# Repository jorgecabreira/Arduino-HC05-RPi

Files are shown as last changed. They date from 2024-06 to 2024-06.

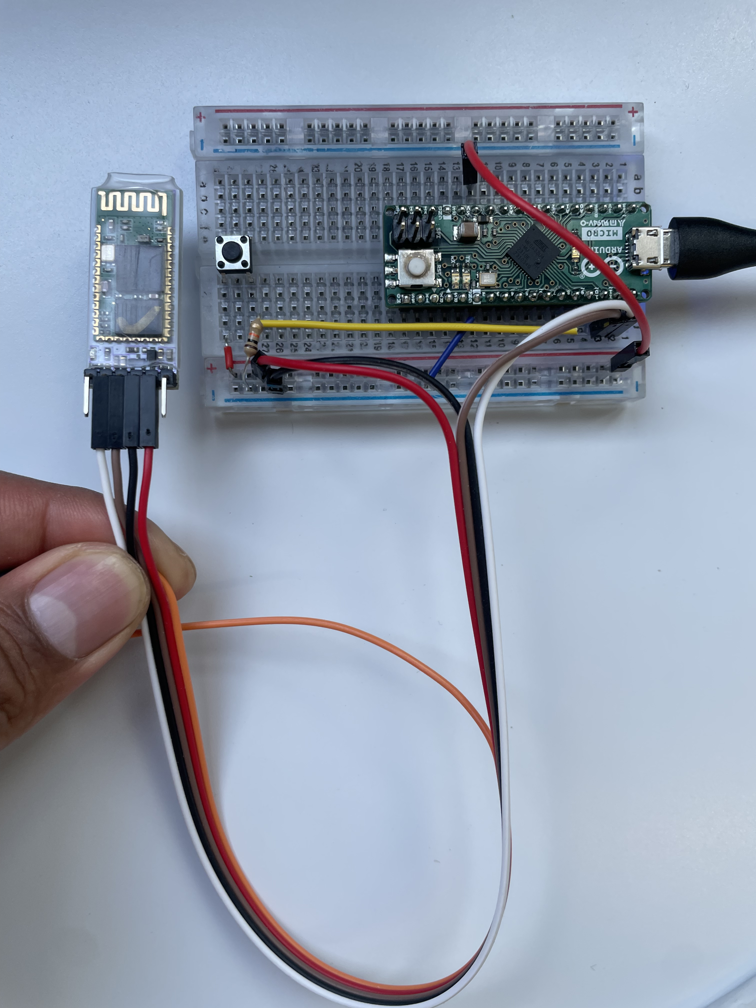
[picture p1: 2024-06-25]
Media/ArduinoMicro.jpeg

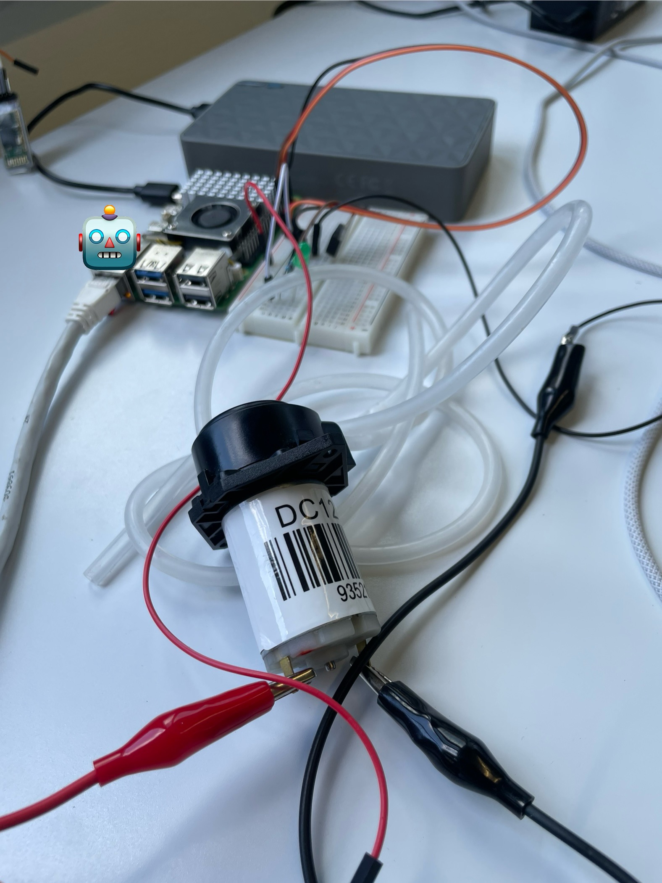
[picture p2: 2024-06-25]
Media/RPi5-PUMP.JPEG

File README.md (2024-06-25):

# Arduino-HC05-RPi
Basic connection between arduino UNO/Micro and Raspberry Pi5 through HC-05 module (Bluetooth).

The idea is to have a central computer (server) that will constantly monitor the state of a button
control by an arduino (client), upon a button press the RPi will then trigger a pump. 
The communication is achieved using a HC-05 module connected to the Arduino. The RPi will use its 
embedded Bluetooth module.

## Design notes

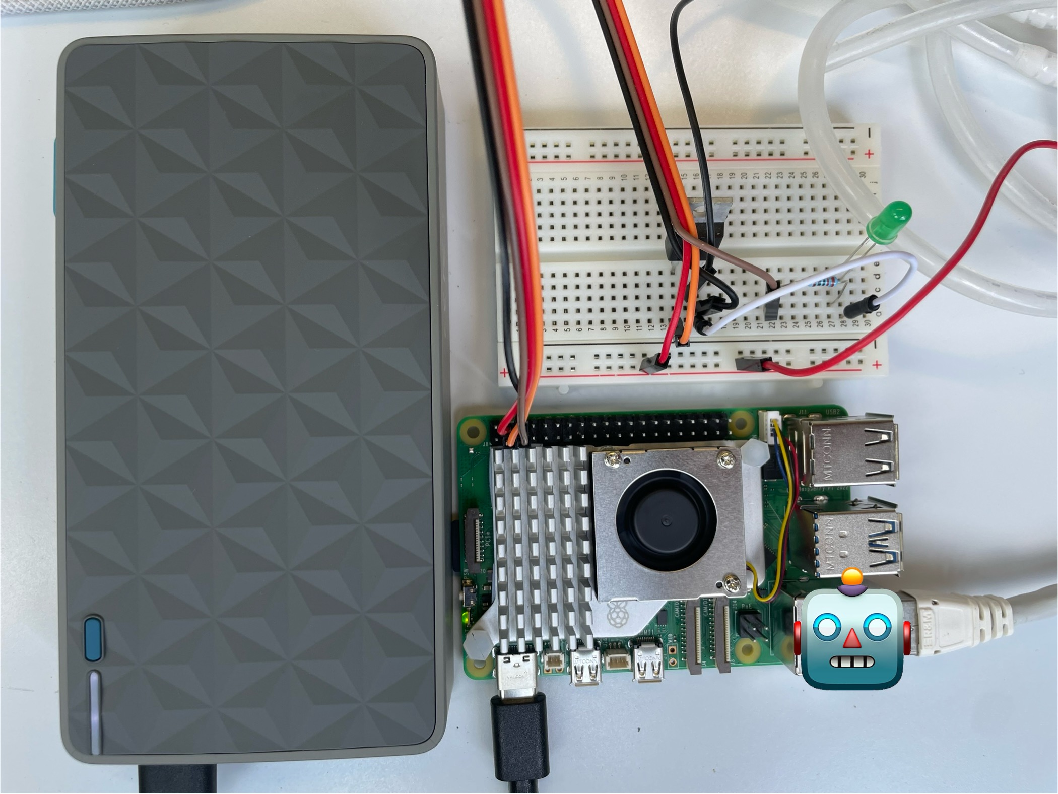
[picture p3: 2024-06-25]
Media/RPi5-TOP.JPEG

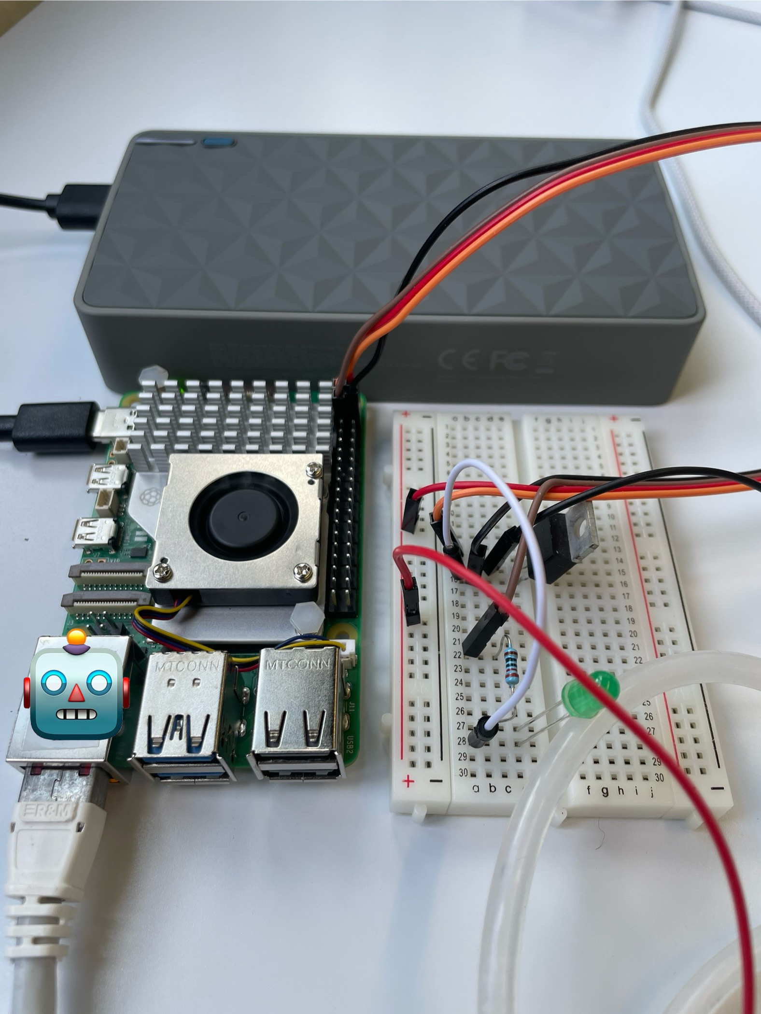
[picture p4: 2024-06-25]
Media/RPi5-SIDE.JPEG

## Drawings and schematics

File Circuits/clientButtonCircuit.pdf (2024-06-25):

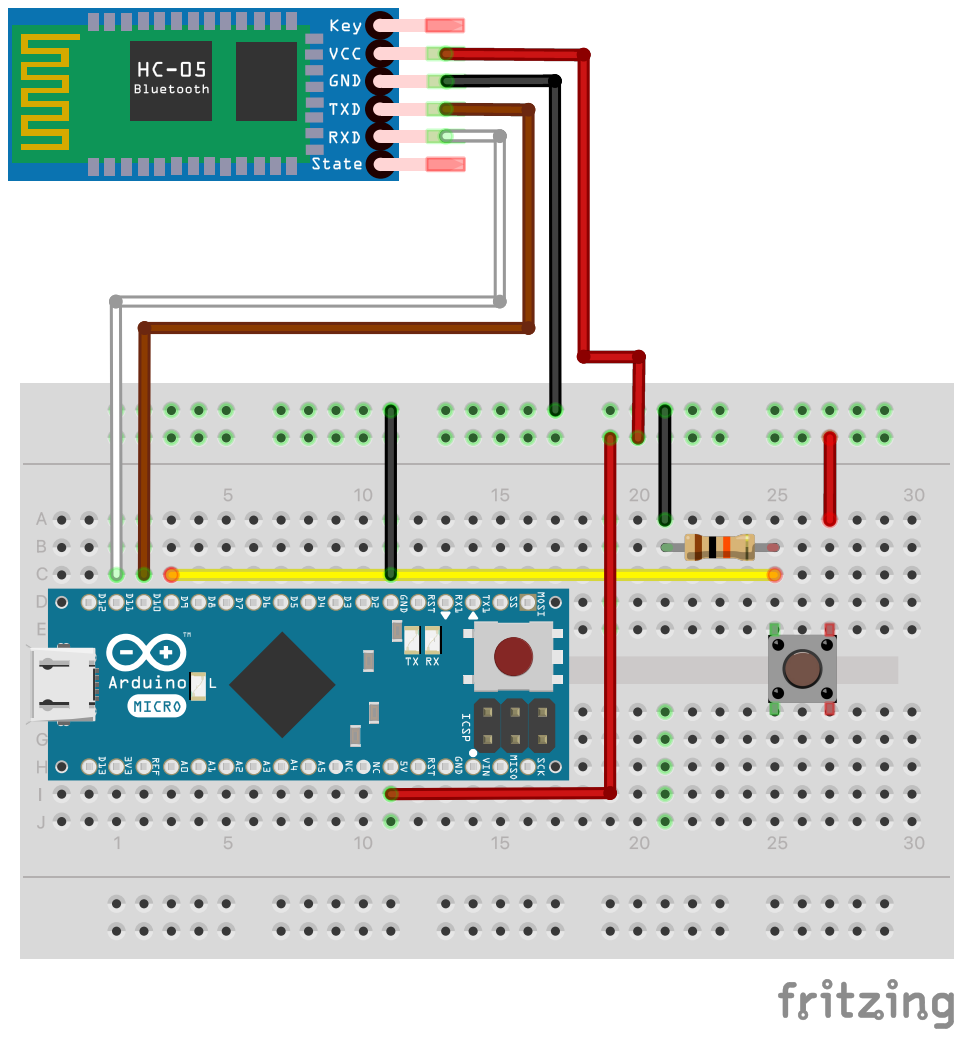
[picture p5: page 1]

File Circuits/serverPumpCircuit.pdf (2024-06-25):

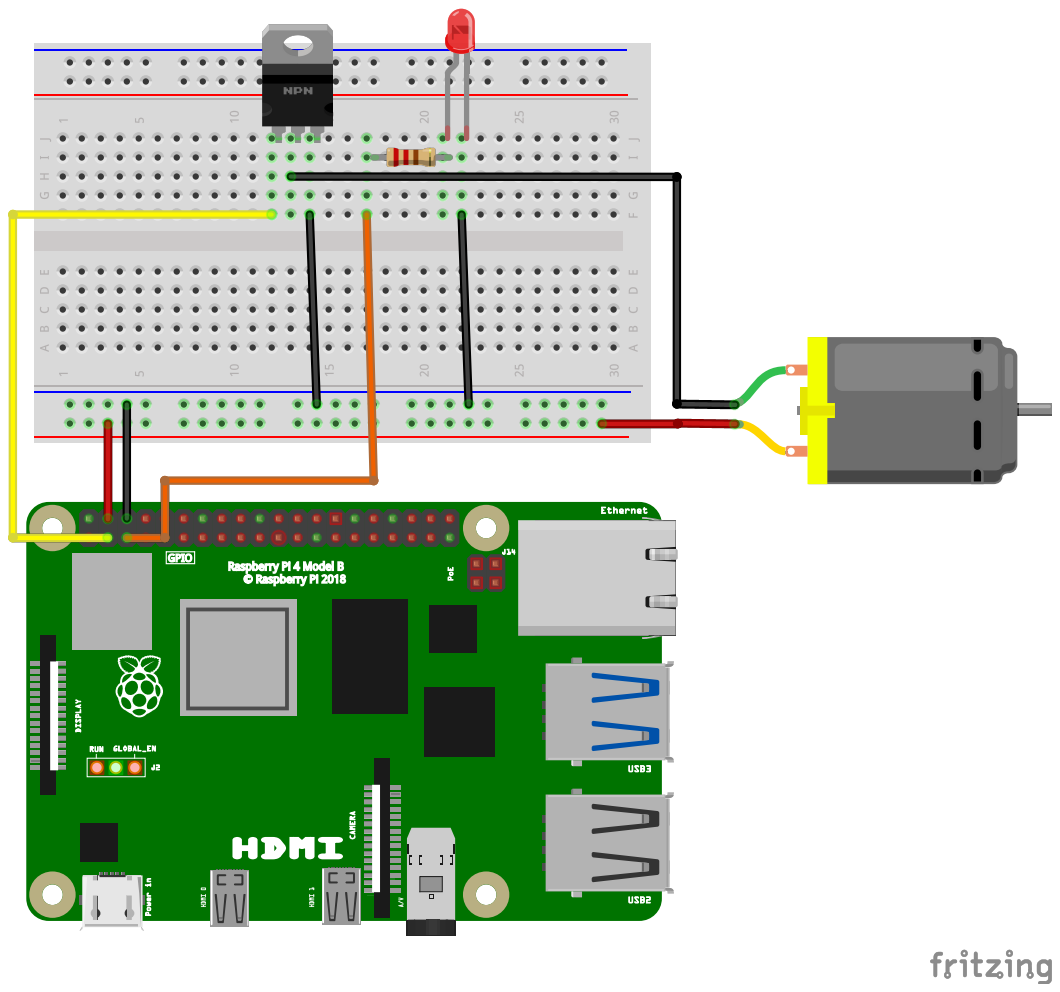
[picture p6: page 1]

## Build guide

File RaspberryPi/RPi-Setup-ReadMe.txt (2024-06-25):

1//Process conduted in a RPi Zero2 with Bookworm 
//Install the necessary dependencies to work with the bluetooth protocol
$sudo apt install -y pi-bluetooth bluetooth bluez picocom blueman python3-pip

2// Edit Bluetooth service
$ sudo nano /etc/systemd/system/dbus-org.bluez.service

3// Once open search fo the section [Service] and add the following lines
// In RPi5 and RPiz2 with Bookworm the first line was already there. Then just add the -C at the end
ExecStart=/usr/lib/bluetooth/bluetoothd -C
ExecStartPost=/usr/bin/sdptool add SP

4// Reload system units
$ sudo systemctl daemon-reload

5// Enable Bluetooth service
$ sudo systemctl enable --now bluetooth

6// In both RPi5 and RPiz2 with Bookworm I got the following error
perl: warning: Please check that your locale settings:
	LANGUAGE = (unset),
	LC_ALL = (unset),
	LC_CTYPE = "UTF-8",
	LANG = "en_GB.UTF-8"
    are supported and installed on your system.
perl: warning: Falling back to a fallback locale ("en_GB.UTF-8").
// I solved it by adding manually the language and the LC_ALL as follows:
// Edit the following file /etc/default/locale by adding
LANG=en_GB.UTF-8
LC_CTYPE=en_GB.UTF-8
LC_MESSAGES=en_GB.UTF-8
LC_ALL=en_GB.UTF-8

// EXTRA ERROR//
// If it keeps printing the previous error I run the following lines and usually solves the problem
export LANGUAGE=en_US.UTF-8
export LANG=en_US.UTF-8
export LC_ALL=en_US.UTF-8
locale-gen en_US.UTF-8

//EXTRA ERROR//
// Another error appeared
Failed to start bluetooth.service: Unit bluetooth.service has a bad unit file setting.
See system logs and 'systemctl status bluetooth.service' for details.
// I found out that I forgot to add the Post in ExecStartPost section 3

7// Enable Bluetooth service
$ sudo systemctl enable --now bluetooth

8// Edit the next file to load rfcomm automatically
$ sudo nano /etc/modules-load.d/modules.conf
// Add the following line
rfcomm

9// Reboot the system

// Pair with the HC-05 Module
10// Turn on the already setup Arduino
11// Access the bluetooth console in the RPi
$ sudo bluetoothctl 

12// Pair with bluetooth module
[bluetooth]# agent on
[bluetooth]# scan on
  Discovery started
  [NEW] Device 98:D3:31:50:4A:C1 98-D3-31-50-4A-C1
  [CHG] Device 98:D3:31:50:4A:C1 LegacyPairing: no
  [CHG] Device 98:D3:31:50:4A:C1 Name: ARDUINOBT
  [CHG] Device 98:D3:31:50:4A:C1 Alias: ARDUINOBT

[bluetooth]# pair 98:D3:31:50:4A:C1
  Attempting to pair with 98:D3:31:50:4A:C1
  [CHG] Device 98:D3:31:50:4A:C1 Connected: yes
  Request PIN code
  [agent] Enter PIN code: 1234
  [CHG] Device 98:D3:31:50:4A:C1 UUIDs: 00001101-0000-1000-8000-00805f9b34fb
  [CHG] Device 98:D3:31:50:4A:C1 ServicesResolved: yes
  [CHG] Device 98:D3:31:50:4A:C1 Paired: yes
  Pairing successful
  [CHG] Device 98:D3:31:50:4A:C1 ServicesResolved: no
  [CHG] Device 98:D3:31:50:4A:C1 Connected: no

[bluetooth]# trust 98:D3:31:50:4A:C1
  [CHG] Device 98:D3:31:50:4A:C1 Trusted: yes
  Changing 98:D3:31:50:4A:C1 trust succeeded

[bluetooth]# exit

13// Create a serial device
$ sudo rfcomm bind rfcomm0 <device's MAC>

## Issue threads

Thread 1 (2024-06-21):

LED signaling

jorgecabreira, 2024-06-21:
Implement the LED in both sides of the rig.
Both LEDs must be blinking until the BLE is achieved between both ends (Arduino and RPi)

jorgecabreira, 2024-06-24:
Try to implemented at boot but it is most straightforward to blink once it is connected and then turn the LED off and at the same time save some energy

jorgecabreira, 2024-06-25:
SOLVED!, for arduino decided to not implemented since is redundant

jorgecabreira, 2024-06-25:
solved

Closed 2024-06-25.

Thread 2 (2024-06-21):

Faster ReactionTime

jorgecabreira, 2024-06-21:
The pump right now is being activated with a considerable delay. The response time needs to be better for the animals to associate easier the push of the button and the reward delivery

jorgecabreira, 2024-06-25:
Seem to get faster reaction times now with the new pushbutton configuration. But the pump stopped working. Need to double check in the RPi

jorgecabreira, 2024-06-25:
SOLVED, it might have been the new arrangement for the button that speed up the readings, transmission and trigger of pump. I use 5V with a digital pin INPUT and to ground with a 10K between the pin INPUT and the ground

Closed 2024-06-25.

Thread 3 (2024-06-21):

Pressed events remained stored

jorgecabreira, 2024-06-21:
When the button has been pressed and the pump is not being triggered somehow next time the connection is successful the pump is being triggered for the number of button presses that were registered in the past.

NEED TO CLEAR BUFFER or whatever that is

jorgecabreira, 2024-06-25:
Keep an eye on it. It might not be present anymore due to the arrangement of the button

jorgecabreira, 2024-07-16:
SOLVED

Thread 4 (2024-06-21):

Pump event log

jorgecabreira, 2024-06-21:
The pump loggings have to relate the moment in which the pump is ON and OFF.
date,object, action
230909,button,pressed
239430,pump,on
323243,pump,off

jorgecabreira, 2024-06-24:
Done!

Closed 2024-06-24.

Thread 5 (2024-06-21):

Button Lock

jorgecabreira, 2024-06-21:
the button press has to be lock until the arduino receives the signal from the raspi that the pump is off and the it is ready to take the next round

jorgecabreira, 2024-06-25:
Solved, by increasing the delay during button pressed it is possible to clock the button until given time

Closed 2024-06-25.

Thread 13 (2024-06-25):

Try Program in RPiz2

jorgecabreira, 2024-06-25:
Try the same program in a Raspberry Pi Z2

jorgecabreira, 2024-06-25:
Not working the RPi zero 2 w is too slow

Closed 2024-06-25.

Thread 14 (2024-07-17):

Implement Flex sensor

jorgecabreira, 2024-07-17:
The flex sensor has to be installed in the seesaw mechanism and then be calibrated to the system now could be trigger by the seesaw movement

Closed 2024-07-24.

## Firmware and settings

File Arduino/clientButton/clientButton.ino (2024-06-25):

// Created on Tue Jun 25 2024 10:23

// @author: J. Cabrera-Moreno
// Postdoctoral Fellow
// Evolutionary Cognition Group
// Institue for Evolutionary Anthropology
// University of Zurich

// Description:
//   The following code pairs the ArtduinoUNO with a RaspberryPi
//   through a HC05 module (Bluetooth Module).
//   The Arduino will act as a client sending information about 
//   the state of a button. That will eventually trigger a pump
//   on the server side.

#include <SoftwareSerial.h>

// Define software serial pins for Bluetooth communication
SoftwareSerial btSerial(10, 11); // RX, TX

// Buffer strings for serial communication
String serialBuffer, btSerialBuffer;

// Define the button pin
const int buttonPin = 9;
int buttonState = 0;

void setup() {
  // Initialize the button pin as an input
  pinMode(buttonPin, INPUT);

  // Initialize the hardware serial communication
  Serial.begin(9600);
  Serial.println("Start serial communication");

  // Initialize the Bluetooth serial communication
  btSerial.begin(115200);
}

void loop() {
  // Read the state of the button
  buttonState = digitalRead(buttonPin);

  // If the button is pressed
  if (buttonState == HIGH) {
    // Print the button state to the serial monitor
    Serial.println(buttonState);

    // Send a message to the Raspberry Pi via Bluetooth
    btSerial.println("Button pressed\r");

    // Small delay to debounce the button and avoid multiple readings
    delay(5000);

    // Do not let the loop end until the button is released
    while (buttonState == HIGH){
      // Read the state of the button
      buttonState = digitalRead(buttonPin);
      delay(1);
    }
  }
}

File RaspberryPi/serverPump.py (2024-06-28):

#!/usr/bin/env python3
# -*- coding: utf-8 -*-
"""
Created on Sat Jun 15 22:32:23 2024

@author: J.Cabrera-Moreno
Postdoctoral Fellow
Evolutionary Cognition Group
Institute of Evolutionary Anthropology
University of Zürich

Description:
    The following code pairs with an Arduino client via Bluetooth
    using a HC-05 module. The Arduino client monitors the state of
    a button that upon press sends a message via Bluetooth to the
    Raspberry Pi which is read by this code. Then when the message
    arrives this code logs the time and the event (ButtonPressed 
    or RewardDelivered).
"""

import time
import serial
import atexit
from multiprocessing import Process
from gpiozero import OutputDevice, LED
from FileManager import FileManager

# Initialize GPIO for pump control
pinPump = OutputDevice(2)
pinLED  = LED(3)
fBlink  = 0.1
sBlink  = 7
# Seconds for the pump to run
rewardTime = 5 # seconds

# LED blink loop
def LEDsignal():
	for i in range(15):
		pinLED.on()
		time.sleep(fBlink)
		pinLED.off()
		time.sleep(fBlink)
	pinLED.on()
	time.sleep(sBlink)
	pinLED.off()
# Function to clean up GPIO
def cleanup():
    pinPump.close()  # Close GPIO pin

# Register cleanup function with atexit
atexit.register(cleanup)

# Initialize serial communication with Arduino
try:
    ser = serial.Serial(
        port='/dev/rfcomm0',
        baudrate=115200,
        parity=serial.PARITY_ODD,
        stopbits=serial.STOPBITS_TWO,
        bytesize=serial.SEVENBITS
    )
    # Ensure the serial port is open    
    if ser.isOpen():
        print("Serial port is open")
	# Starts LED blinking for some seconds to indicate that the BLE 
	# connection was successful
        Process(target=LEDsignal).start()

except serial.SerialException as e:
    print(f"Error opening serial port: {e}")
    exit(1)  # Exit the program if serial port cannot be opened

# Initialize file manager
directory = '~/Desktop/DATA'  # Replace with pertinent directory
file_manager = FileManager(directory)
file_path = file_manager.create_file()
print(f"File created: {file_path}")

# Main loop to handle Arduino communication
try:
    while True :
        if ser.inWaiting() > 0:
            recv = ser.readline()
    
            if recv != '':
		        # Log button pressed to file
                formattedDateTime = file_manager.get_current_datetime(False)
                file_manager.log_to_file(file_path,f"{formattedDateTime},button,pressed")
                print("Arduino status: " + str(recv, 'utf-8'))
                
                # Activate pump, log pump on to file
                pinPump.on()
                formattedDateTime = file_manager.get_current_datetime(False)
                file_manager.log_to_file(file_path,f"{formattedDateTime},pump,on")
                time.sleep(5)
                
		        # Turns off pump and logs pump off to file
                pinPump.off()
                formattedDateTime = file_manager.get_current_datetime(False)
                file_manager.log_to_file(file_path,f"{formattedDateTime},pump,off")
		    
                # Send reply to Arduino with successful pump activation
                response = "Pump activated\r"
                ser.write(response.encode())
                print("Response sent: Pump activated")


except KeyboardInterrupt:
    print("Program terminated by user")
except Exception as e:
    print(f"Exception ocurred: {e}")
finally:
    # Cleanup: Close serial port
    if ser.isOpen():
        ser.close()
        print("Serial port closed")

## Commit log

2024-06-24 Add the LEDsignaling to the clientPump.py in the RPi. Still missing a similar behavior in the Arduino
    [clientPump.py]
2024-06-24 update serverPump.py
    there were some indentation issues with some lines. The code was edited in the gitweb
    [serverPump.py]
2024-06-24 Update serverPump.dy
    Issues with indentation. There were quite long empty spaces. I delete them and add a tab on each
    [serverPump.py]
2024-06-25 update clientButton.ino
    re-wrote the code for arduino
2024-06-25 Update clientButton.ino
    Made sure that the button is just triggers once every 5s so the animals can not trigger the pump if the decide to stay in the button longer
2024-06-25 Created electronic circuits
    [clientButtonCircuit.fzz, serverPumpCirtuit.fzz]
2024-06-25 update name
    [clientButtonCircuit.fzz, serverPumpCirtuit.fzz]
2024-06-28 Updated the serverPump.py file from RPiz2 and added ~/ to the path so now it can be run from any raspberry pi
